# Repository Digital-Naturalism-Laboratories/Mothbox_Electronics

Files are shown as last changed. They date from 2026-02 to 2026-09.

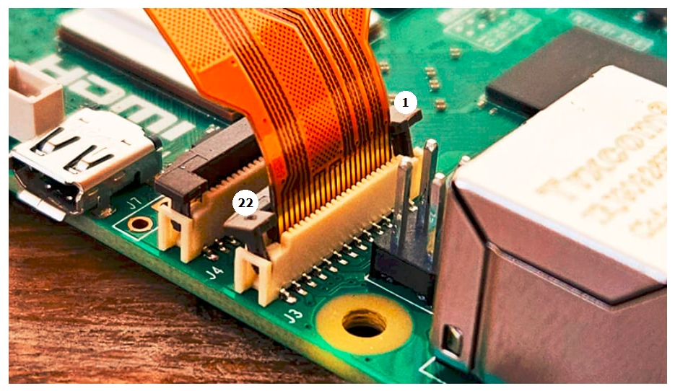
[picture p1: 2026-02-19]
Mothbox_PCBs/Mothbox_PCB_5.0.6/MothBox/Mothbox_5.0.4/RPi5-HATplus-master/img/CSI2_FFC_numbering.jpg

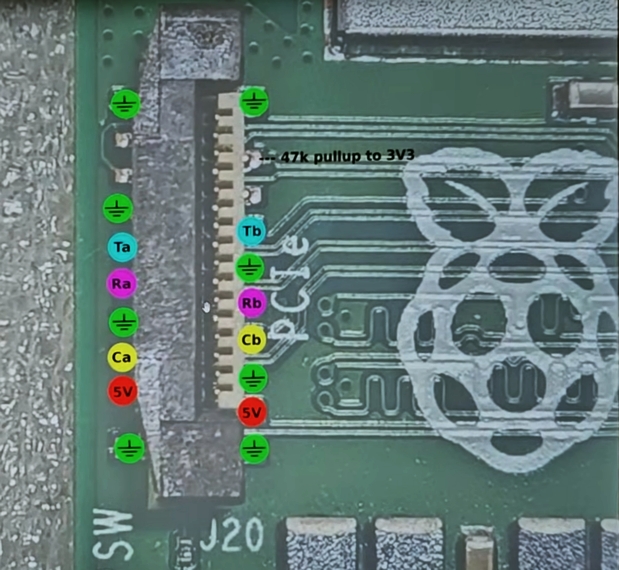
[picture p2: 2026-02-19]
Mothbox_PCBs/Mothbox_PCB_5.0.6/MothBox/RPi5-HATplus-master/img/George_Smart_PCIe_reversing.jpg

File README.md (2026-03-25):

# Mothbox_Electronics
This is where the electronics for the Mothbox are developed, such as the PCB! It's copied over from https://github.com/Digital-Naturalism-Laboratories/Mothbox/tree/main/Hardware/PCB so you can check that out if you want to see the full history!

Here's some current specs on the PCB 





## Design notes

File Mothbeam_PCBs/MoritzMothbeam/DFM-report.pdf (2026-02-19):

Single PCB View - Original

Top View | Bottom View

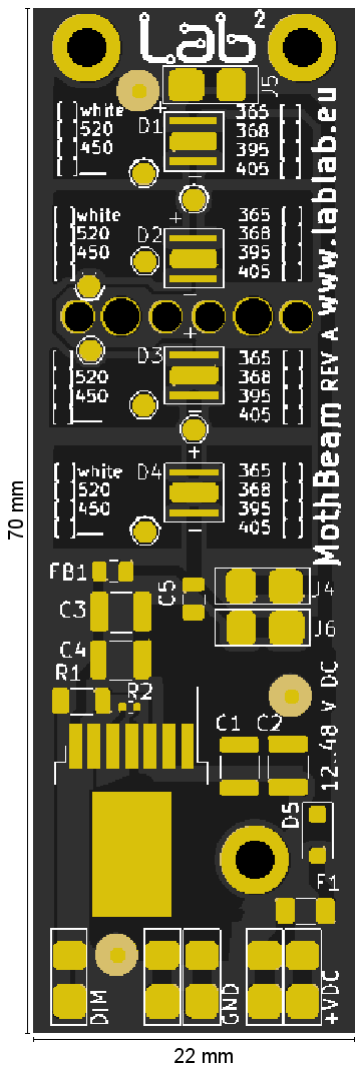
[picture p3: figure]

Summary - General - Original

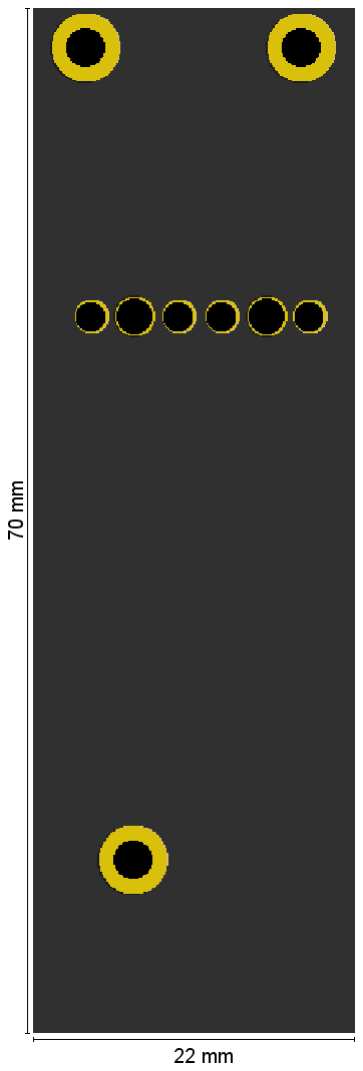
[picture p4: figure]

PCB Size | 22 mm x 70 mm | Customer Panel Size
PCB Thickness | 1.6 mm | Max. Aspect Ratio on PTH | 0.8
Copper Layers | 2 | Pressing Stages | 1
Surface Finish | unknown | Drill Hole Density | 58 Holes/dm²
Solder Mask | Both | Testable Points | 84
Solder Mask Color | Green | Min. SMD/BGA Size | 0.48 mm
Legend | Top Only | !HolesInPadPth! | No
Legend Color | White | !HolesInPadBlind! | No
Edge Connector Area | 0 dm² | Stacked Vias
Peeloff Mask | No | Castellated | No
Carbon Mask | No | Anomalies | No
1 | 2 | 3 | 4 | 5 | 6 | 7 | 8 | 9

Summary - Copper Layer Minima - Original

Type | Copper Width | Critical Copper Width

Trace Width Critical Trace

| | | | Width | Copper to Copper Clr. | Trace to Trace Clr. | Same Net Clr. | Ring | Copper to Outline Clr.
| mm | mm | mm | mm | mm | mm | mm | mm | mm
Outer | 0.250 | 0.250 | 0.250 | 0.250 | 0.235 | 0.341 | 0.380 | 0.150 | 0.314
Integr8tor v2023.12-240208 | Page1

The information on this document is not only based on files in a clearly defined format, but also on freely structured files and inference rules. CircuitHub strives to make it as accurate as possible, but it cannot guarantee the result in all situations. This information is used at the sole risk of its user.

Name | rev_57895.zip | Id. | 18720 - QED With Image Data
Report Generated on | Jul 8, 2024, 2:59:33 PM | Customer
Board Id | | Article Id

10 | 11 | 12

Summary - Copper Layer Minima - Original

Type | Copper to Plated Clr. | Copper to NPTH Clr.
!Min.Clr.Overal
l!

!Min.Clr.toPad! !Min.Clr.toTrac e!

!Min.Clr.toRegi
on!

!Min.Clr.Overal
l!

!Min.Clr.toPad! !Min.Clr.toTrac e!

!Min.Clr.toRegi
on!
mm | mm | mm | mm | mm | mm | mm | mm
Outer | 0.447 | 0.459 | 0.447 | >0.800
Inner

Summary - Sequences - Original

Type | Sequences | Tools | Min. End
| | | Dia. | Max. End Dia.
Holes | Routs | Ring on
| | | | | | | Outer

Ring on
Inner
| | | | | | | | Hole to Copper Clr.
mm | mm | mm | mm | mm
PTH | 1 | 3 | 2.000 | 2.700 | 9 | 0 | 0.150 | 0.447
Total | 1 | 3 | 2.000 | 2.700 | 9 | 0 | 0.150 | 0.447

Summary - Rout - Original

Type | Tools | Min. End Dia. | Max. End Dia. | Rout Length
| | | | | mm | | mm | mm
Plated
NPTH

Total

Board Id | Article Id

Stackup - Original

Pressing Stages | 1

Files - Original

Initial | Renamed | Function | Position | Color | Thickness
Base | Finished
| | | | | mm | mm
stencil-top.pho | paste-top | paste | top
silkscreen-top.pho | silk-top | silk | top | white | unknown | unknown
solder-mask-top.pho | mask-top | mask | top | black | unknown | unknown
copper-top.pho | top | outer | 1 | | | 0.035 | unknown
copper-bottom.pho | bot | outer | 2 | | | 0.035 | unknown
solder-mask-bottom.pho | mask-bot | mask | bottom | black | unknown | unknown
drill-npth.pho | pth_1 | plated | 1-2
drill.pho | pth | plated | 1-2
outline.pho | outline | cad_outline | none
silkscreen-bottom.pho | silkscreen-bottom_pho | empty | none
stencil-bottom.pho | stencil-bottom_pho | empty | none

PCB (Single) - Original

PCB Size | Outline Type | Outline Length | Outline Area | Copper Layers | PCB Thickness
mm x mm | | mm | dm² | | mm
22.000 x 70.000 | real | 184.000 | 0.1540 | 2 | 1.600

Customer Panel (Delivery Array, Assembly Panel) - Original

Original Image | Panel Size | Left | Right | Top | Bottom | X Spacing | Y Spacing | PCB's | Depanel Rout Length
| mm x mm | mm | mm | mm | mm | mm | mm | | mm

Thickness - Original

No license to generate this information.

Board Id | Article Id

Copper Layer Minima & Area - Original

File | Pos. Copper Width | Critical
Copper Width

Trace Width Critical Trace Width

Copper to
Copper Clr.

Same Net
Clr.

Copper Area

mm | mm | mm | mm | mm | mm | dm² | %
top | 1 | 0.250 | 0.250 | 0.250 | 0.250 | 0.235 | 0.380 | 0.0897 | 58
bot | 2 | >0.400 | >0.400 | >0.400 | >0.400 | 0.450 | >0.500 | 0.0081 | 5

Copper Layer Minima - Copper to Drill Minima - Original

File | Pos. | Ring | Copper to Drill Clr. | Copper to Outline Clr.
Overall | Via | Laser Via Comp. | Mech. | Plated | NPTH | Overall | to Pad | to Trace | to Region
mm | mm | mm | mm | mm | mm | mm | mm | mm | mm | mm
top | 1 | 0.150 | 0.150 | 0.447 | 0.314 | 0.314 | 1.243 | 1.054
bot | 2 | 0.150 | 0.150 | 0.600 | 0.314 | 0.314 | >1.600 | >1.600

Copper Layers - Copper to Copper Clearances - Original

File | Pos. | Copper to Copper Clr.
Overall | Pad to Pad | Pad to Track | Track to Track | Trace to Trace
mm | mm | mm | mm | mm
top | 1 | 0.235 | 0.309 | 0.235 | 0.341 | 0.341
bot | 2 | 0.450 | 0.450 | >0.500 | >0.500 | >0.500

Copper Areas - Original

Side | Total | Free of | Edge Connectors
Solder Mask
(as supplied)

Solder Mask
(open vias)
Gold Mask Silver Mask | Fingers | Finger Size | Total Area

dm²

dm²

dm²

dm²

dm² | mm x mm | dm²
Top (incl. 1/2 plated holes and routs) | 0.0911 | 0.0321 | 0.0321
Bottom (incl. 1/2 plated holes and routs) | 0.0094 | 0.0094 | 0.0094
Total (incl. plated holes and routs) | 0.1005 | 0.0415 | 0.0415 | 0
Plated holes and routs | 0.0106 | 0.0106 | 0.0106
Top (without plated holes and routs) | 0.0858 | 0.0268 | 0.0268
Bottom (without plated holes and routs) | 0.0041 | 0.0041 | 0.0041
Total (without plated holes and routs) | 0.0899 | 0.0309 | 0.0309

Drill Tools - Original

File | Tool
Nr.
Span | Type | Function Method Filled Via | Counter | Dia. | Tol. - | Tol. + Holes
in PCB

Routs
in PCB

Double
Hits

Predrill
Hits
mm | mm | mm
pth | 10 | 1-2 PTH | comp. | mech. | unknown unknown | 2.700 0.000 0.000 | 3 | 0 | 0 | 0
pth_1 | 10 | 1-2 PTH | comp. | mech. | unknown unknown | 2.000 0.000 0.000 | 4 | 0 | 0 | 0
pth_1 | 11 | 1-2 PTH | comp. | mech. | unknown unknown | 2.500 0.000 0.000 | 2 | 0 | 0 | 0
Board Id | Article Id

Drill Tools - Drill vs Copper - Original

File | Tool
Nr.
Span | Type | Function Method | Dia. Ring on
Outer

Ring on
Inner

Min.
Pad
Size

Via in
Pad

Plated to Copper Clr.
!Min.Clr
.Overall
!

!Min.Clr
.toPad!

!Min.Clr
.toTrac
e!

!Min.Clr
.toRegi
on!
mm | mm | mm | mm | mm | mm | mm | mm
pth | 10 | 1-2 PTH | comp. | mech. | 2.700 >0.800 | > 4.300 | >0.800 | >0.800 | >0.800 | >0.800

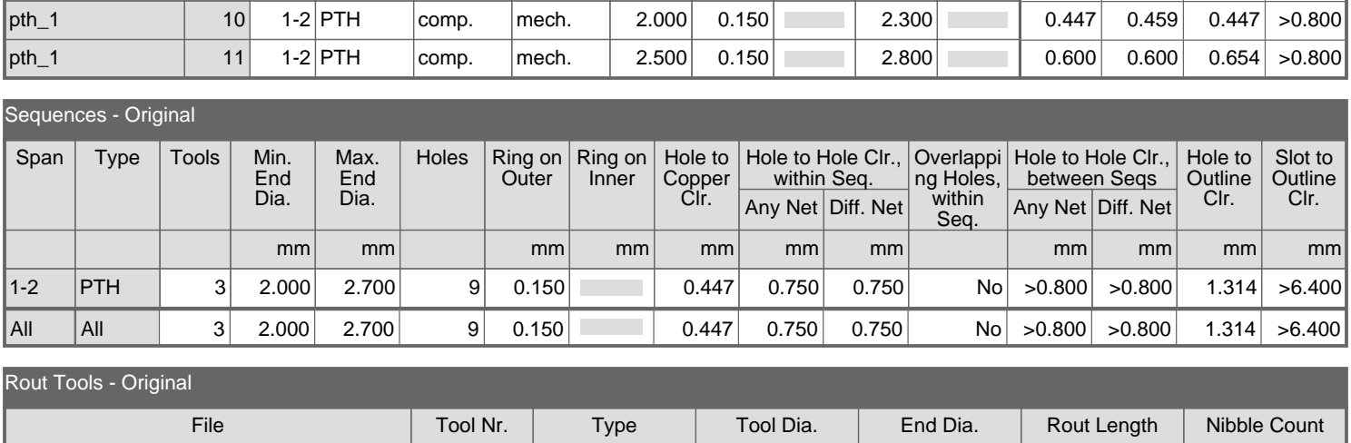
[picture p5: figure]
pth_1; 1-2 PTH; comp.; mech.; Sequences - Original; Span; Type; Tools; Min.; End Dia.; Max. End Dia.; Holes Ring on Outer; Ring on Inner; Hole to Copper Clr.; Hole to Hole Clr., within Seq.; Overlappi ng Holes, within Seq.; Hole to Hole Clr., between Seqs; Hole to Outline Clr.; Slot to Outline; Clr. Any Net Diff. Net; Any Net Diff. Net; PTH; All; Rout Tools - Original; File; Tool Nr.; Tool Dia.; Rout Length; Nibble Count

mm | mm | mm

Routed Holes - Original

File | Hole Nr. | Instances | X Size | Y Size | Rout Length | Nibble Count
mm | mm | mm

Sequences Analysis - Original

File | Pos. Stacked
Vias
| Overlap ped Vias | Via Plug Clr.
Top Tool | Bottom Tool
Top Drill File | Tool Nr. | Dia. | Bottom Drill File Tool Nr. | Dia.
| | mm | | mm | | mm

SMD (Incl. BGA) - Original

| SMD (Incl. BGA) | SMD (Excl. BGA) | | | BGA
Side | Pads | Min. Pad Pitch of Min.
| Pad | Solder Mask Defined Pads
Pads | Pads | Min. Pad | Min. Pitch | All Tracks
| | | | | Centered | Drilled Pads
mm | mm | mm | mm
Top | 66 | 0.480 | 2.770 | 0 | 66 | 0
Bottom | 0 | | | 0 | 0 | 0
Both | 66 | | | 0 | 66 | 0
Board Id | Article Id

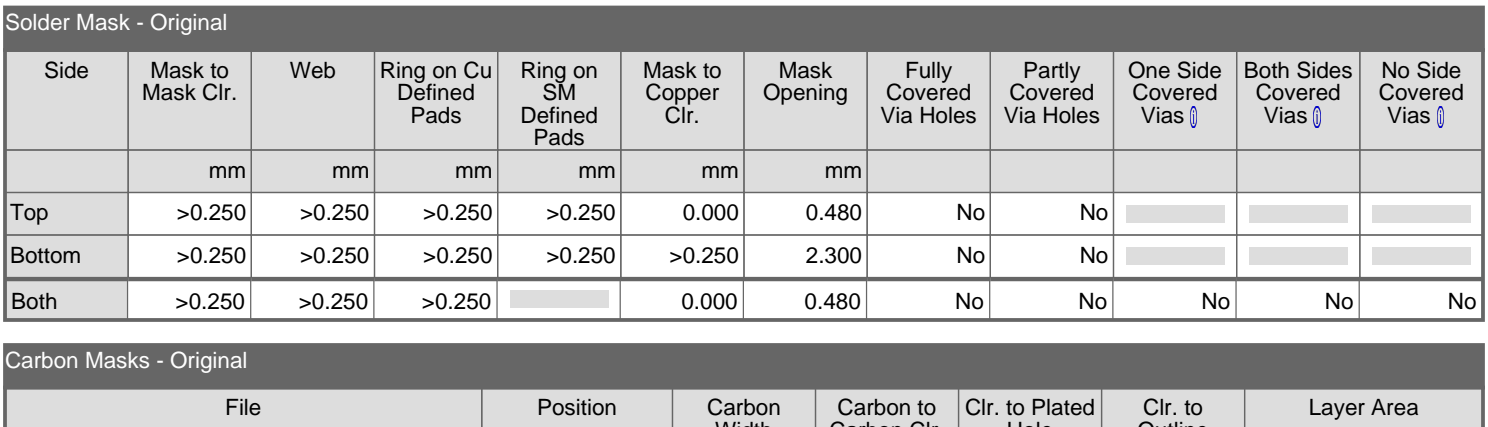
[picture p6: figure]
Solder Mask - Original; Side; Mask to; Mask Clr.; Web; Ring on Cu; Defined Pads; Ring on SM Defined Pads; Mask to Copper Clr.; Mask Opening; Fully Covered Via Holes; Partly Covered Via Holes; One Side Covered Vias; Both Sides Covered Vias; No Side Covered Vias; Top; Bottom; Both; Carbon Masks - Original; File; Position; Carbon; Carbon to; Clr. to Plated; Clr. to; Layer Area

Width

Carbon Clr.

Hole

Outline
mm | mm | mm | mm | dm² | %

Peeloff Masks - Original

File | Position | Min.
Peelable
Width

Peelable to
Peelable Clr.

Clr. to Plated
Hole

Clr. to
Outline

Layer Area

mm | mm | mm | mm | dm² | %

Legend Layers - Original

File | Position | Legend Width | Legend to
Legend Clr.

Legend to
(Comp/SMD/BGA)
Pad Clr.

Layer Area

mm | mm | mm | dm² | %
silk-top | top | 0.100 | 0.009 | 0.049 | 0.0126 | 8

Gold Layers - Original

File | Position | Gold to Gold Clr. | Clr. to Outline | Layer Area
mm | mm | dm² | %

Heatsink Layers - Original

File | Position | Heatsink to
Heatsink Clr.
Clr. to Outline | Layer Area
mm | mm | dm² | %

Scoring - Minimum Clearance - Original

No license to generate this information.

Bare Board Test - Original

Side | Testable Points
(TPs)
Max. TP Density | SMD Pads | Min. SMD Pad | Pitch of Min.
SMD Pad

Edge Connector
Fingers

Number of Nets

TP/dm² | mm | mm
Top | 75 | 809 | 66 | 0.480 | 2.770 | 0
Bottom | 9 | 154 | 0 | 0
Both | 84 | 809 | 66 | 0 | 28
Board Id | Article Id

DFM Classes - Original

| | | Standard | Advanced
1 | 2 | 3 | 4 | 5 | 6 | 7 | 8 | 9
Track & Gap | Min Clearance (Track-Track / Track-Pad / Pad-Pad) | 0.235 | 0.300 | 0.250 | 0.200 | 0.150 | 0.130 | 0.120 | 0.100 | 0.075 | 0.060
| Min Track Width / Thermal Gap | 0.250 | 0.300 | 0.250 | 0.200 | 0.150 | 0.130 | 0.120 | 0.100 | 0.075 | 0.060
Ring for IPC Class 2 | Outer Min Layer Annular Ring | 0.150 | 0.250 | 0.220 | 0.200 | 0.150 | 0.130 | 0.120 | 0.100 | 0.075 | 0.060
| Inner Min Layer Annular Ring | | 0.250 | 0.220 | 0.200 | 0.150 | 0.130 | 0.120 | 0.100 | 0.075 | 0.060
Aspect Ratio | Max Aspect Ratio for Plated Hole | 0.800 | 8.000 | 8.000 | 8.000 | 8.000 | 10.000 | 10.000 | 10.000 | 10.000 | 10.000
Drill - Cu | Distance PTH to PTH | 0.750 | 0.600 | 0.500 | 0.400 | 0.350 | 0.300 | 0.300 | 0.275 | 0.250 | 0.230
Cu Thickness | Max Cu Thickness that can be etched | | 0.175 | 0.140 | 0.105 | 0.070 | 0.070 | 0.035 | 0.035 | 0.035 | 0.017
Solder Mask | Solder Mask Annular Ring | 0.000 | 0.100 | 0.075 | 0.050 | 0.050 | 0.050 | 0.050 | 0.040 | 0.030 | 0.010
| Solder Mask SolderWeb | | 0.150 | 0.125 | 0.100 | 0.100 | 0.100 | 0.100 | 0.080 | 0.075 | 0.075

Input Remarks - Original

Gerber import: Invalid coincident draw, continuing without cleanup 'copper-top.pho'
Layer does not contain any image data (demoted to 'empty') 'silkscreen-bottom_pho'
Layer does not contain any image data (demoted to 'empty') 'stencil-bottom_pho'
Gerber Job File import: DISCREPANCY: Extra top layers mismatch between Gerber Job File and current job stackup.
Gerber Job File import: OMITTED: $.MaterialStackup[6] not added to layer attributes because corresponding layer could not be found.

Customer and Job Identification - Original

Customer
Customer | Contact Person
Email

Customer and Job Identification - Original

Job
Article Id | | Board Id
DPMX Output Path | CH

Comments - Original

Board Id | Article Id

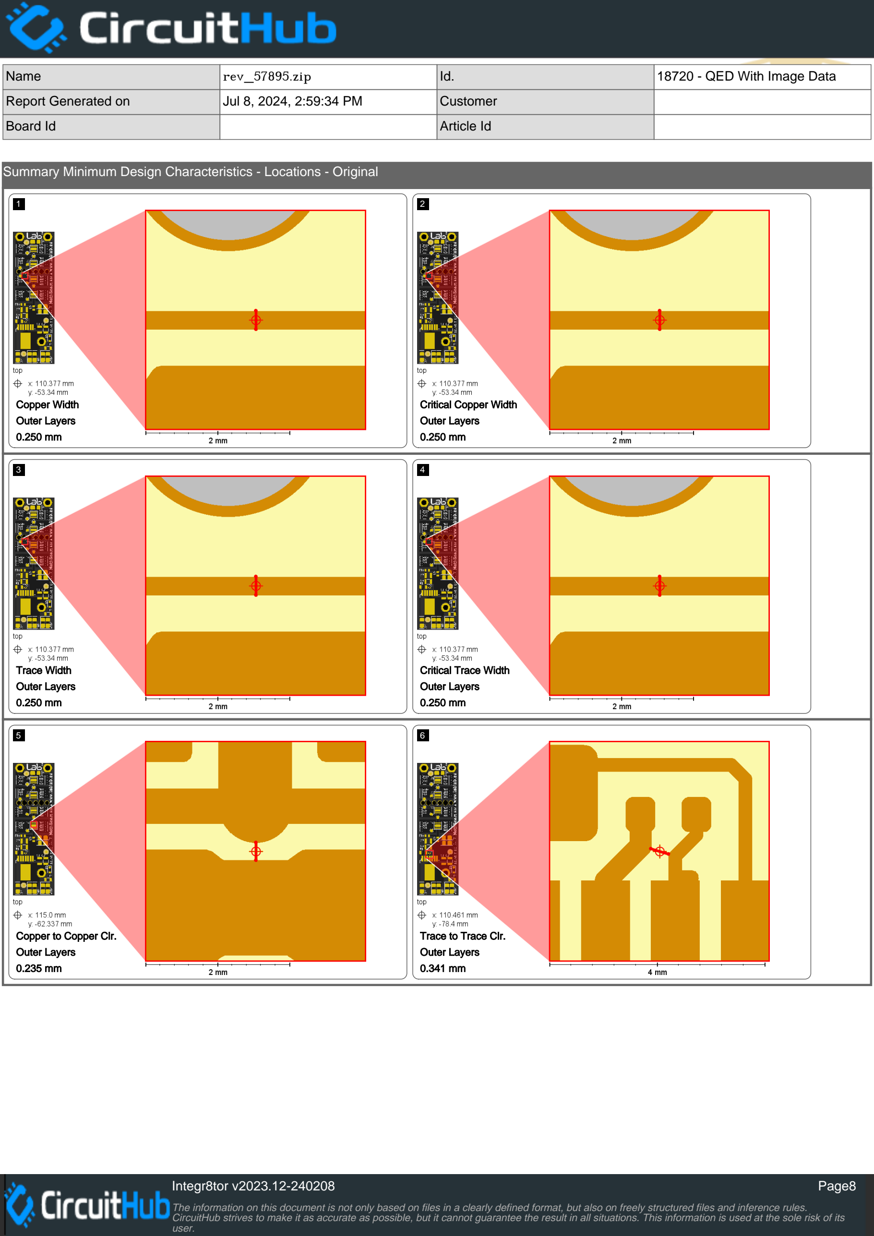
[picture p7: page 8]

1 | 2
3 | 4
5 | 6

Summary Minimum Design Characteristics - Locations - Original

Copper Width
Outer Layers
0.250 mm

Critical Copper Width
Outer Layers
0.250 mm

Trace Width
Outer Layers
0.250 mm

Critical Trace Width
Outer Layers
0.250 mm

Copper to Copper Clr.
Outer Layers
0.235 mm

Trace to Trace Clr.
Outer Layers
0.341 mm
Report Generated on | Jul 8, 2024, 2:59:34 PM | Customer
Board Id | | Article Id

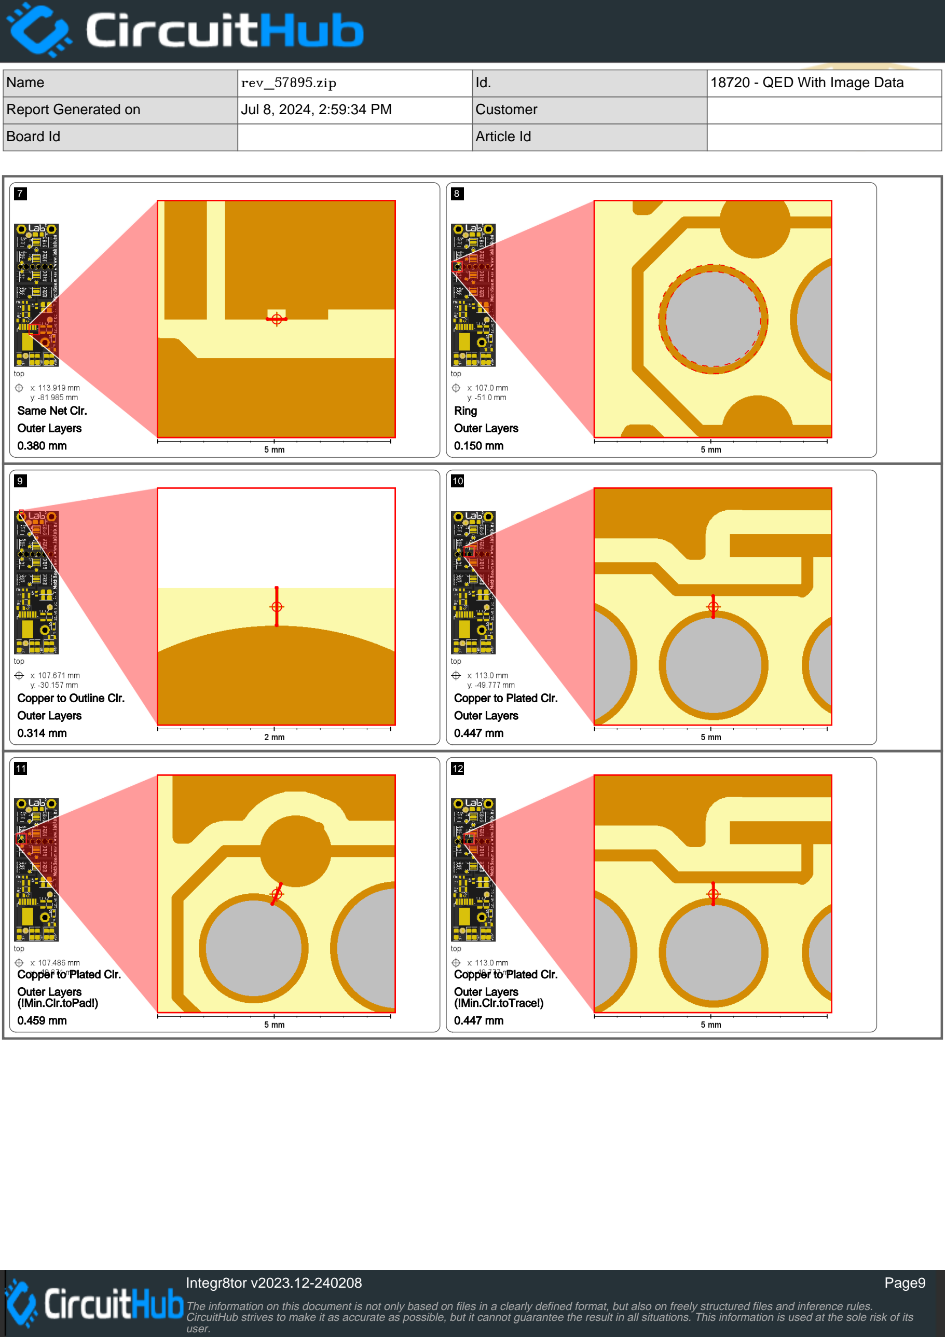
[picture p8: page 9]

7 | 8
9 | 10
11 | 12

Same Net Clr.
Outer Layers
0.380 mm

Ring
Outer Layers
0.150 mm

Copper to Outline Clr.
Outer Layers
0.314 mm

Copper to Plated Clr.
Outer Layers
0.447 mm

Copper to Plated Clr.
Outer Layers
(!Min.Clr.toPad!)
0.459 mm

Copper to Plated Clr.
Outer Layers
(!Min.Clr.toTrace!)
0.447 mm
Report Generated on | Jul 8, 2024, 2:59:34 PM | Customer
Board Id | | Article Id

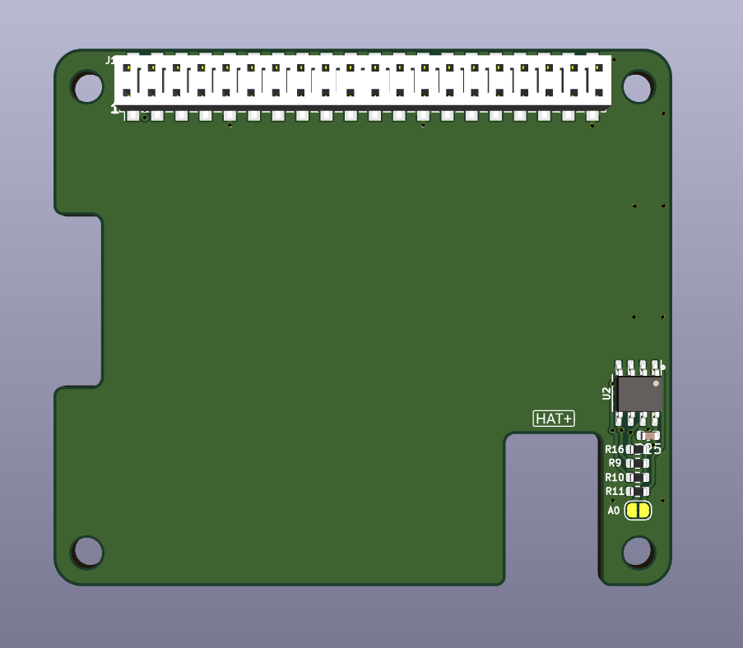
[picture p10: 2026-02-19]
Mothbox_PCBs/Mothbox_PCB_5.0.6/MothBox/Mothbox_5.0.4/MothBox_5.0.3/RPi5-HATplus-master/img/HATPlus_Template.png

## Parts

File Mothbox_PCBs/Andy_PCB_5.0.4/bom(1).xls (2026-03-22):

Comment | topDesignator | bottomDesignator | Footprint | JLCPCB Part #
5A47uH |  | L1 | L_Chilisin_BMRG00131360 | C497913
LTR-303ALS-01 | U18 |  | Lite-On_LTR-303ALS-01 | C364577
XL-5730UWC-05 | LED1,LED10,LED11,LED12,LED13,LED14,LED15,LED16,LED17,LED18,LED19,LED2,LED20,LED21,LED22,LED23,LED24,LED25,LED26,LED27,LED28,LED29,LED3,LED30,LED31,LED32,LED33,LED34,LED35,LED36,LED37,LED38,LED39,LED4,LED40,LED41,LED42,LED43,LED44,LED45,LED46,LED47,LED48,LED49,LED5,LED50,LED51,LED52,LED53,LED54,LED6,LED7,LED8,LED9 |  | LED-SMD_3P-L5.7-W3.0-RD | C2843887
AP30P30Q |  | Q1,Q10,Q13,Q8 | PDFN3333-8_L3.1-W3.2-P0.65-LS3.4-BL | C471913
10uF | C1,C19,C20,C21 | C10,C11,C17,C18,C8 | C_0603_1608Metric | C19702
100K |  | R38,R41,R42 | R_0603_1608Metric | C25803
3.0K |  | R3,R34 | R_0603_1608Metric | C4211
KH-6X6X5H-STM |  | SW2 | KEY-SMD_4P-L6.0-W6.0-P4.50-LS10.0-TL | C592734
GPs5pinPM2.54-1*5 |  | U8 | PinSocket_1x05_P2.54mm_Vertical | C5116488
10K | R11,R9 | R1,R19,R2,R21,R27,R31,R35,R36 | R_0603_1608Metric | C25804
Hours3 |  | U12,U10,U14,U13,U11 | SW-SMD_SMXS-08K-TP | C5439767
0.033R/1% |  | R4 | R_2512_6332Metric | C875726
YJQ10N2A | Q3,Q7 | Q4,Q5,Q6,Q9 | U-DFN2020-6_L2.0-W2.0-P0.65-BL | C919558
PCA9555PW |  | U15,U16,U9 | TSSOP-24_4.4x7.8mm_P0.65mm | C128392
Conn_1.25mm |  | J5 | CONN-SMD_3P-P1.25_DF13C-3P-1.25V | C88352
18R | R10,R12,R13,R14,R15,R16,R17,R18,R20,R22,R23,R24,R25,R26,R28,R37,R7,R8 |  | R_1210_3225Metric | C422378
RASPBERRY_PI_5 | U5 |  | EPAPER_PinHeader_2x20_P2.54mm_Vertical | C5224014
INA219BIDCNT |  | U3 | SOT-23-8 | C87469
DS18B20U |  | U17 | MSOP-8_L3.0-W3.0-P0.65-LS4.9-BL | C695836
SK54C |  | E1 | SMC_L6.9-W5.9-LS8.0-RD | C5449119
GPS4pin2.54-1*4P |  | H1 | PinSocket_1x04_P2.54mm_Vertical | C2718488
XL4015E1 |  | U2 | TO-263-5_TabPin3 | C51661
470uF50V |  | C14,C16 | CAP-SMD_BD12.5-L13.0-W13.0-RD | C90272
Green |  | D3 | LED_0603_1608Metric | C965804
DB141V-2.54-4P |  | J1,J2,J3,J4 | CONN-TH_4P-P2.54_DIBO_DB141V-2.54-4P | C2898746
AO3400A |  | Q2 | SOT-23 | C2938367
7Atrip |  | F2 | Fuse_2920_7451Metric | C22363536
4.7K |  | R29,R30,R33,R39,R5,R6 | R_0603_1608Metric | C23162
100R |  | R32 | R_0603_1608Metric | C21189
0.1uF | C13 | C2,C3,C5,C12,C15,C4,C6,C7,C9 | C_0603_1608Metric | C14663
18V |  | D1,D2,D4 | D_SOD-123 | C382948
FemaleInvSocketPi2.54-2*20 |  | U7 | HDR-TH_40P-P2.54-H-F-R2-C20-W8.5 | C2897440
PZ254R-12-8P | H10,H8,H9 |  | HDR-TH_8P-P2.54-H-M-R2-C4-S2.54 | C7501618

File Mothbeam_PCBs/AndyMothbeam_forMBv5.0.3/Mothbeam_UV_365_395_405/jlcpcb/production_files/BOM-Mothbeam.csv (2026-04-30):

Comment | Designator | Footprint | LCSC | Quantity
5.1 1/3 W | R1,R2,R3,R4,R5,R6,R9 | R_0603_1608Metric | C2907045 | 7
BCR421U | U1,U2,U3 | SOT-23-6_L2.9-W1.6-P0.95-LS2.8-BL | C194382 | 3
LED1 | D1 | LED-SMD_3P-L3.5-W3.5-R-RD-C | C2833504 | 1
LED2 | D2 | LED-SMD_3P-L3.5-W3.5-R-RD-C | C2833576 | 1
LED3 | D3 | LED-SMD_3P-L3.5-W3.5-R-RD-C | C2833578 | 1
SW_DIP_x04 | SW2 | SW-SMD_8P-L6.7-W5.4-P1.27-LS8.5 | C319050 | 1
X6511FRS-04-C85D30 | CN1 | HDR-SMD_4P-P2.54-H-F | C5142237 | 1

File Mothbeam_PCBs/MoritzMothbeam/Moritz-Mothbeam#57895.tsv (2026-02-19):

Description | ID | Manufacturer | Manufacturer Part Number | Supplier | Supplier Part Number | Reference Designators | Line Quantity | Order Quantity | Unit Price | Order Price | Legacy ID | Mounting Type
DNP | DNP |  |  |  |  | H4,H5,H6,H7,H8,H9,TP8,TP6,TP4,TP2,TP7,TP1,TP3,TP5,R2,H2,H3,FID1,FID2,FID3
Rectifier Diode Schottky 1A Automotive 2-Pin SOD-123F T/R / DIODE SCHOTTKY 60V 1A SOD123F | NEXPERIA/PMEG6010CEH,115 | Nexperia | PMEG6010CEH,115 | Newark | 75R0892 | D5 | 1 | 22 | 0.1050 | 2.3100 |  | Surface mount
Fuse Chip Fast Acting 1A 32V SMD Solder Pad 1206 Glass T/R VDE/cULus | SCHURTER/3413.0216.22 | Schurter | 3413.0216.22 | Digi-Key | 486-1144-6-ND | F1 | 1 | 9 | 0.9380 | 8.4420 |  | Surface mount
Ultraminiature Slim Contact; Poke-In Connector; SMT; Wire-to-Board; 20-24 AWG | TC/2834171-3 | TE Connectivity | 2834171-3 |  |  | J6,J4,J5,J2,J8,J3,J1,J7 | 8 | 50 | 0.0504 | 2.5200 |  | Surface mount
Uv Emitter, 365Nm, Uva, 1W, Top View Smd Rohs Compliant: Yes |Wurth Elektronik 15335337AA350 | W/15335337AA350 | Würth Elektronik | 15335337AA350 | Digi-Key | 732-15335337AA350DKR-ND | D1 | 1 | 5 | 21.3080 | 106.5400 |  | Surface mount
Single Color LED, Ultra Violet, Water Clear, 2.6mm | W/15335339AA350 | Würth Elektronik | 15335339AA350 |  |  | D3,D2 | 2 | 10 | 8.4700 | 84.7000 |  | Surface mount
Single Color LED, Ultra Violet, Water Clear, 2.6mm | W/15335340AA350 | Würth Elektronik | 15335340AA350 | Mouser | 710-15335340AA350 | D4 | 1 | 5 | 17.2200 | 86.1000 |  | Surface mount
WPME-LDHM LED Step Down High Current Module | W/172946001 | Würth Elektronik | 172946001 | Digi-Key | 732-6218-6-ND | U1 | 1 | 5 | 9.9680 | 49.8400 |  | Surface mount
WE-CBF Ferrite Bead 0805 1500Ohm 1000mA | Wurth Elektronik 742792097 | W/742792097 | Würth Elektronik | 742792097 | Digi-Key | 732-4649-1-ND | FB1 | 1 | 15 | 0.2940 | 4.4100 |  | Surface mount
0.1μF ±10% 100V Ceramic Capacitor X7R 0805 (2012 Metric) | W/885012207128 | Würth Elektronik | 885012207128 | Digi-Key | 732-12244-6-ND | C5 | 1 | 15 | 0.1232 | 1.8480 |  | Surface mount
4.7μF ±10% 50V Ceramic Capacitor X7R 1210 (3225 Metric) | W/885012209048 | Würth Elektronik | 885012209048 | Mouser | 710-885012209048 | C1,C2,C3,C4 | 4 | 24 | 1.8200 | 43.6800 |  | Surface mount
GENERAL PURPOSE CHIP RESISTOR Metal Glaze/thick Film, 0.25W, 0ohm, Surface Mount, 1206 | YAGEO/RC1206JR-070RL | Yageo | RC1206JR-070RL | Newark | 26M6809 | R1 | 1 | 100 | 0.0182 | 1.8200 |  | Surface mount

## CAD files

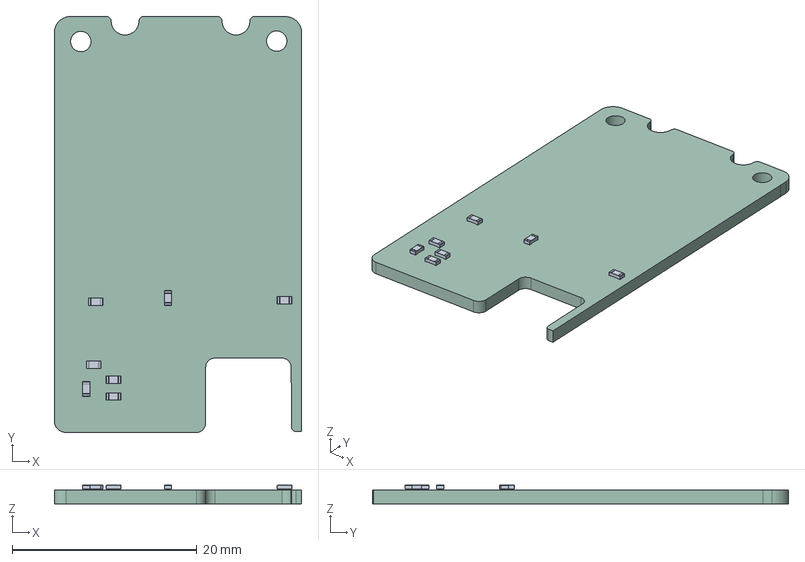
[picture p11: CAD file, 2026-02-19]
Mothbeam_PCBs/AndyMothbeam_forMBv5.0.1/Mothbeam_UV_365_395_405/Mothbeam-v5.0.1.step
26.8 x 45.0 x 2.04 mm
R_0603_1608Metric x 7
SOT-23-6_L2.9-W1.6-H1.5-LS2.8-P0.95 x 3
Mothbeam_PCB

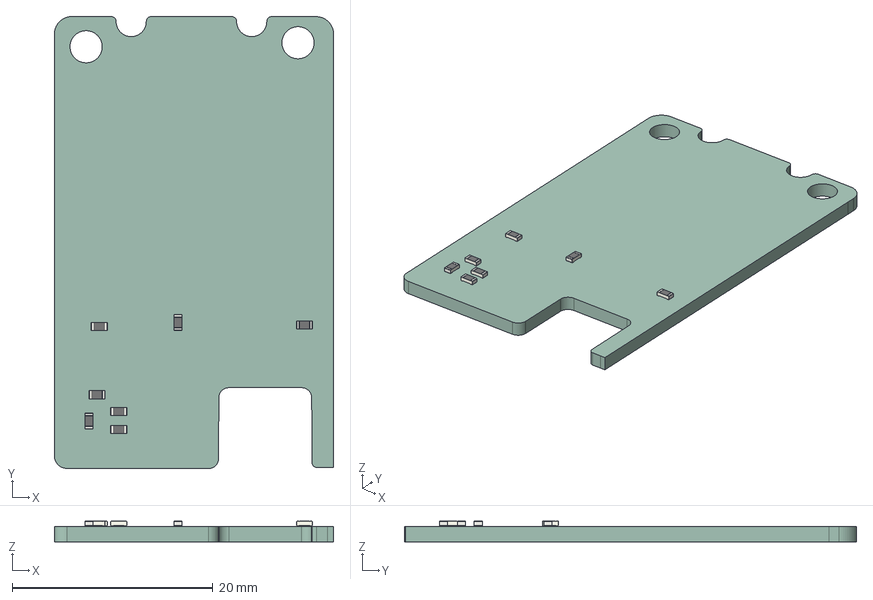
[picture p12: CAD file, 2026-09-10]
Mothbeam_PCBs/AndyMothbeam_forMBv5.0.3/Mothbeam_UV_365_395_405/Models_And_Designs/Mothbeam.step
27.8 x 45.0 x 2.04 mm
R_0603_1608Metric x 7
Mot78B0_PCB

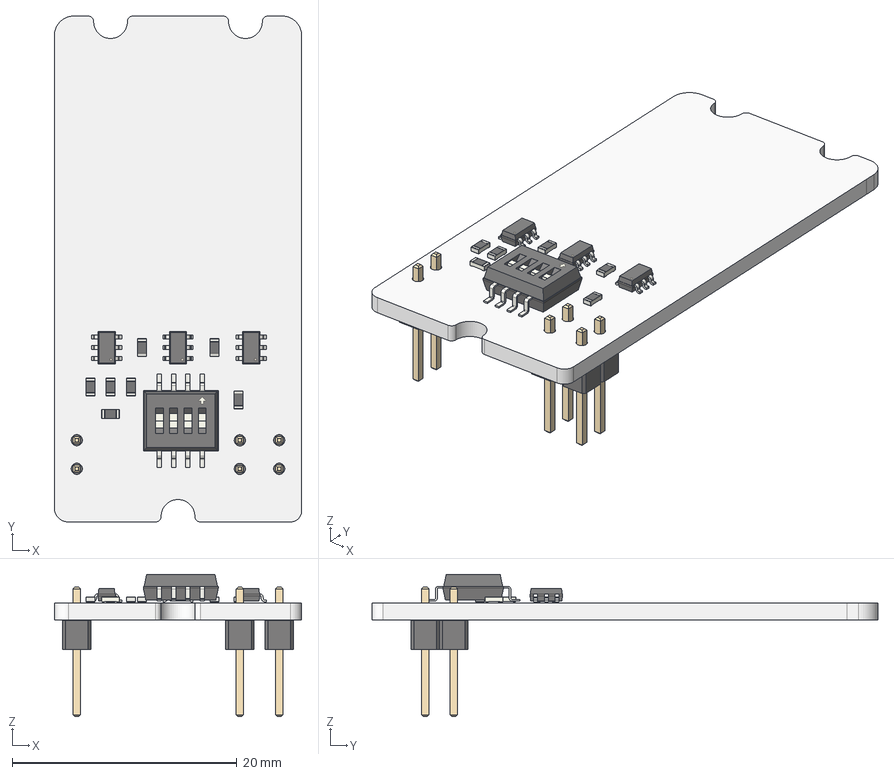
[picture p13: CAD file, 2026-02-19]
Mothbox_PCBs/Mothbox_PCB_5.0.6/MothbeamAttractor/MothbeamAttractor.step
22.0 x 45.0 x 12.7 mm
SW_DIP_SPSTx04_Slide_KingTek_DSHP04TS_W7.62mm_P1.27mm
R_0603_1608Metric x 7
SC-74-6_1.55x2.9mm_P0.95mm x 3
PinHeader_1x02_P2.54mm_Vertical x 3
MothbeamAttractor_PCB

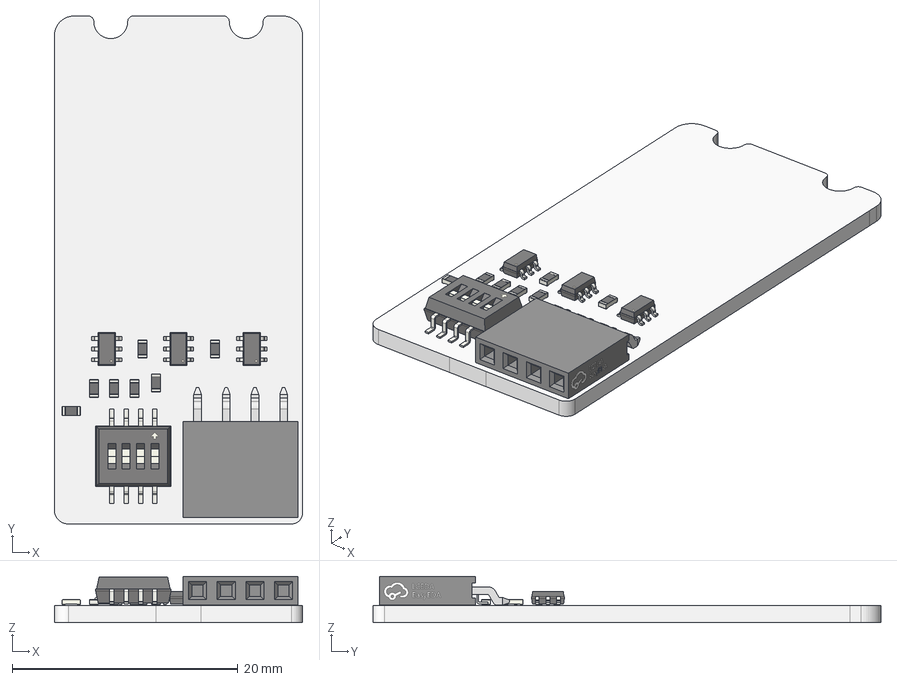
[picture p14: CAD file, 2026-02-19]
Mothbox_PCBs/Mothbox_PCB_5.0.6/MothbeamAttractor_FemaleHeader/MothbeamAttractorFemale.step
22.0 x 45.0 x 4.12 mm
SW_DIP_SPSTx04_Slide_KingTek_DSHP04TS_W7.62mm_P1.27mm
R_0603_1608Metric x 7
SC-74-6_1.55x2.9mm_P0.95mm x 3
HDR-SMD_4P-P2.54-H-F
MothbeamAttractor_PCB

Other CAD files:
Mothbox_PCBs/Mothbox_PCB_5.0.6/MothBox/Mothbox_5.0.4/CAD/MothBox_v5.0.1_FreeCad_Outline.FCStd
Mothbox_PCBs/Mothbox_PCB_5.0.6/MothBox/CAD/MothBox_v5.0.1_FreeCad_Outline.FCStd
Mothbox_PCBs/Mothbox_PCB_5.0.6/MothBox/Mothbox_5.0.4/MothBox_5.0.3/CAD/MothBox_v5.0.1_FreeCad_Outline.FCStd

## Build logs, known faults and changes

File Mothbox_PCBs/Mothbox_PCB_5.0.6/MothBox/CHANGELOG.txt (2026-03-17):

Project Name: MothBox Main PCB

PCB Versions:
-------------
Version 5.0.5:
Production:  PCBWAY, 2 Layers, 1.6mm, Green, 238mmx141mm 
Date: 2026-03  

Major Changes:
Done: Added second set of holes for mounting battery
Done: added highlights on battery mounting holes
Done: added PCBway logo for pcb sponsorship
Done: Changed labelling on switches to make them confuse JLC people less

Version 5.0.4:
Production:  JLCPCB, 2 Layers, 1.6mm, Green, 238mmx141mm 
Date: 2025-12-  

Major Changes:
Done: reverse Q8
Done: update zener diodes: D1+D2+D4 from 6.8V to 18V so they can cope better with 36V input voltages. Add a 100K ohm resistor to help with lower voltages
Done: Changed footprints of d1 d2 d4 to SOD 123 for bigger diode (AQ)
Done: swapped out C14+C16 for smaller 470uF 50V SMD Caps.  The 1000uF ones are too high and easily damaged
Done: swapped out R32 0R to 100R so that the RPi voltage is reduced from 5.40V to 5.25V

Minor changes:
Done: Change Attractor Mounting holes to m3 from m2.5 to make it easier to zip tie (AQ)
Done: Added 3D models for capacitors (AQ)
Done: Scootch SN QR code a bit so there's space for text code + QR code (AQ)
Done: rotate LED 49 to just give it a bit more breathting room away from attractor 2 (AQ)
Done: Moved Battery attaching zip tie holes around to avoid box conflict, and better battery holding (AQ)
Done: add some extra label to Documentation QR code
Done: add extra label to 12V testpoint to clarify that it's under software control
Done: minor Ground layer revamps
Done: added extra text to Power supply schematic to clarify 5V volt supply/resistor selection
Done: added a note about cutting JP1 if people want to measure the current

Version 5.0.3:
Production:  JLCPCB, 2 Layers, 1.6mm, Green, 238mmx141mm 
Date: 2025-11-20-ish  (uploaded by Andy to JLCPCB)

Major Changes:
Done: swap out the 12V vgs JMTV210P02A P-MOSFETs (Q1, Q8, Q10) for 20V Vgs based AP30P30Q - C471913
Done: change fuse from 1812 3A to 2920 7A?  Have to move IAN219 over a bit
Done: decrease IAN219 sense resistor from 0.1 ohm to 0.033 ohm
Done: Remove the D7, D6, D5, D2 ESD diodes.  Otherwise, increase from 12V, to 18V or 45V? 
Done: replace RPi 1000uF 5V cap with some 10uF caps. Could have used the original 470uF cap?
Done: rotate input power connector 90 deg.
Done: add a closed solder jumper across R4 so we can bypass the current measurements and save on the Voltage drop
Done: add zener to Q8 (12V isolater MOSFET).  Tt should have a 6.8V zener as well as it might have up to 36V across it?
Done: add reverse power protection to the 12V input after J1

Minor Changes:
Done: add double ++-- to the three side power green/orange connector labels and backside
Done: remove old MB: text label and box from backside
Done: fix R + L Flash LED labels to something like: L/R FLASH LED GND?
Done: add Talentcell Battery part numbers? (e.g. PB120B1) and larger font 
Done: whats happening to the two S/N boxes? (AQ - keep the square one, leave space below it (or move it to where it has space below)
Done: cleanup the EXT Temp Sensor label?
Done: move C5 and R33 label around the DS18B20 temp sensor box
Done: change 1.5V text to 1.5A on the external connector
Done: move the 'Active' label on the U11 switch to the RH side.
Done: add --++ label to front side of PCB on the input connector
Done: Add Aducam camera P/N text? Arducam 64MP OV64A40 OwlSight
Done: move and rotate 3V3 line MOSFET labels, + R36, C??
Done: rotate H1 + U8 GPS connector labels. PH: Note I ungrouped the 4 objects
No: make GPS box outline a bit smaller. PH: No, it's a footprint and outlines the size of the GPS board
Done: outline the Battery pack onto the silkscreen layer as a keep out zone
Done: decrease D1 zener from 10V to 6.8V. We need to be able to take 36V!!  Our zener can take up to 5mA.  We should pass 2.5mA max through 14.7K at 36V.
Done: bold up ambient light sensor text 
Done: rotate U18 ref label
Done: re-arrange front/back side graphics and text
Done: moved some of the traces a bit away from under the sides of the L1 inductor

Version 5.0.2:
Production:  JLCPCB, 2 Layers, 1.6mm, Green, 238mmx141mm 
Date: 2025-09-TBD  (uploaded by Andy)

Done: AQ- swapped green indicator LED (C72043) which LCSC says is discontinued  for  C2289 which is dirt cheap and plentiful
Done: AQ - change the user switch to use the ALWAYS on 3v3 power so that a user could always be able to push it, and then it could trigger a script to enable the other 3.3v
Done: AQ - scoot items out of where batteries might be
Done: Silkscreen - we should put the test point labels on both sides of the board
Done: add a user switch
Done: add a user LED
Done: MOSFET switch the entire 3V3 line out of the RPi connector to minimise 3.3V quiescent current usage. 
Done: add a SMD DS18B20 PCB temperature sensor
Done: add provision for an external DS18B20 temperature sensor. Need a 4.7K ohm resistor and a 1.25mm 3-pin connector
Done: remove 3V3 input leading to the ePaper hat connector as it has it's own built in 5V to 3V3 regulator
Done: Swap out the PCA9535 MUX to the PCA9555PW(UMW) as this has pullup resistors: C42420607
Done: fix the two Attractor 3 labels.  One should be #1
Done: can move attractor labels out from under the foot print?
Done: Move resistor R22 out from underneath Attractor 3 footprint
Done: 5v test point is awkwardly under an LED on one side
Done: Silkscreen of regulated 12v is reversed! (Double check other silkscreen labels)
Done: change R3 to a lower value (3K Ohm) so as to raise the voltage to 5.2V for the RPi
Done: add an extra resistor close to R3 (Vf power), so feedback voltage can be easier to fine tune
Done: swap out the BH1750FVI-TR LCSC: C78960 to the cheaper LTR-303ALS-01 ambient light sensor: C364577, US$0.38/ea, DFN-6(2x2)
Done: remove: GPIO4/pin8 from RPi-ePaper.  Reroute to DS18B20
Done: construct a stronger ground plain
Done: Add an extra 6 (2 x 3) Photo LEDs to PCB
Done: added Power input/Output direction arrows for each connector
Done: modified Serial Number Box shape - Andy added another switched it back because JLCPCB needs certain dimensions to automatically put the serial and QR code on

Version 5.0.1: 
Production:  JLCPCB, 2 Layers, 1.6mm, Green, 238mmx141mm 
Date: 2025-05-18 

Done: design and laid out by building on the 5.0.0 design and user feedback
Done: upgraded white LEDs to be twice as bright (500mW)
Done: replaced switch multiplexer IC's with i2C based IC's
Done: added an extra switch bank for another 8 hours of config options
Done: reversed ePaper screen so it's on the other side of PCB
Done: swapped out the MOSFETs for different and cheaper versions
Done: added a reverse polarity protection MOSFET to power input
Done: swapped out the green input connectors from a horizontal to vertical connectors
Done: swapped out the 0805 fuse to a larger 1812 6A fuse
Done: as there are now more i2C IC's on the bus, the i2C pullup resistor values where dropped to 4.7K ohm
Done: added a project URL QR code to the PCB
Done: general clean up of the schematic
Done: add a BH1750FVI-TR light sensor (second v5.0.1 version)

Version 5.0.0: 
Production:  JLCPCB, 2 Layers, 1.6mm, Green, 238mmx141mm 
Date: 2025-05-??

* designed and laid out by AndyQ

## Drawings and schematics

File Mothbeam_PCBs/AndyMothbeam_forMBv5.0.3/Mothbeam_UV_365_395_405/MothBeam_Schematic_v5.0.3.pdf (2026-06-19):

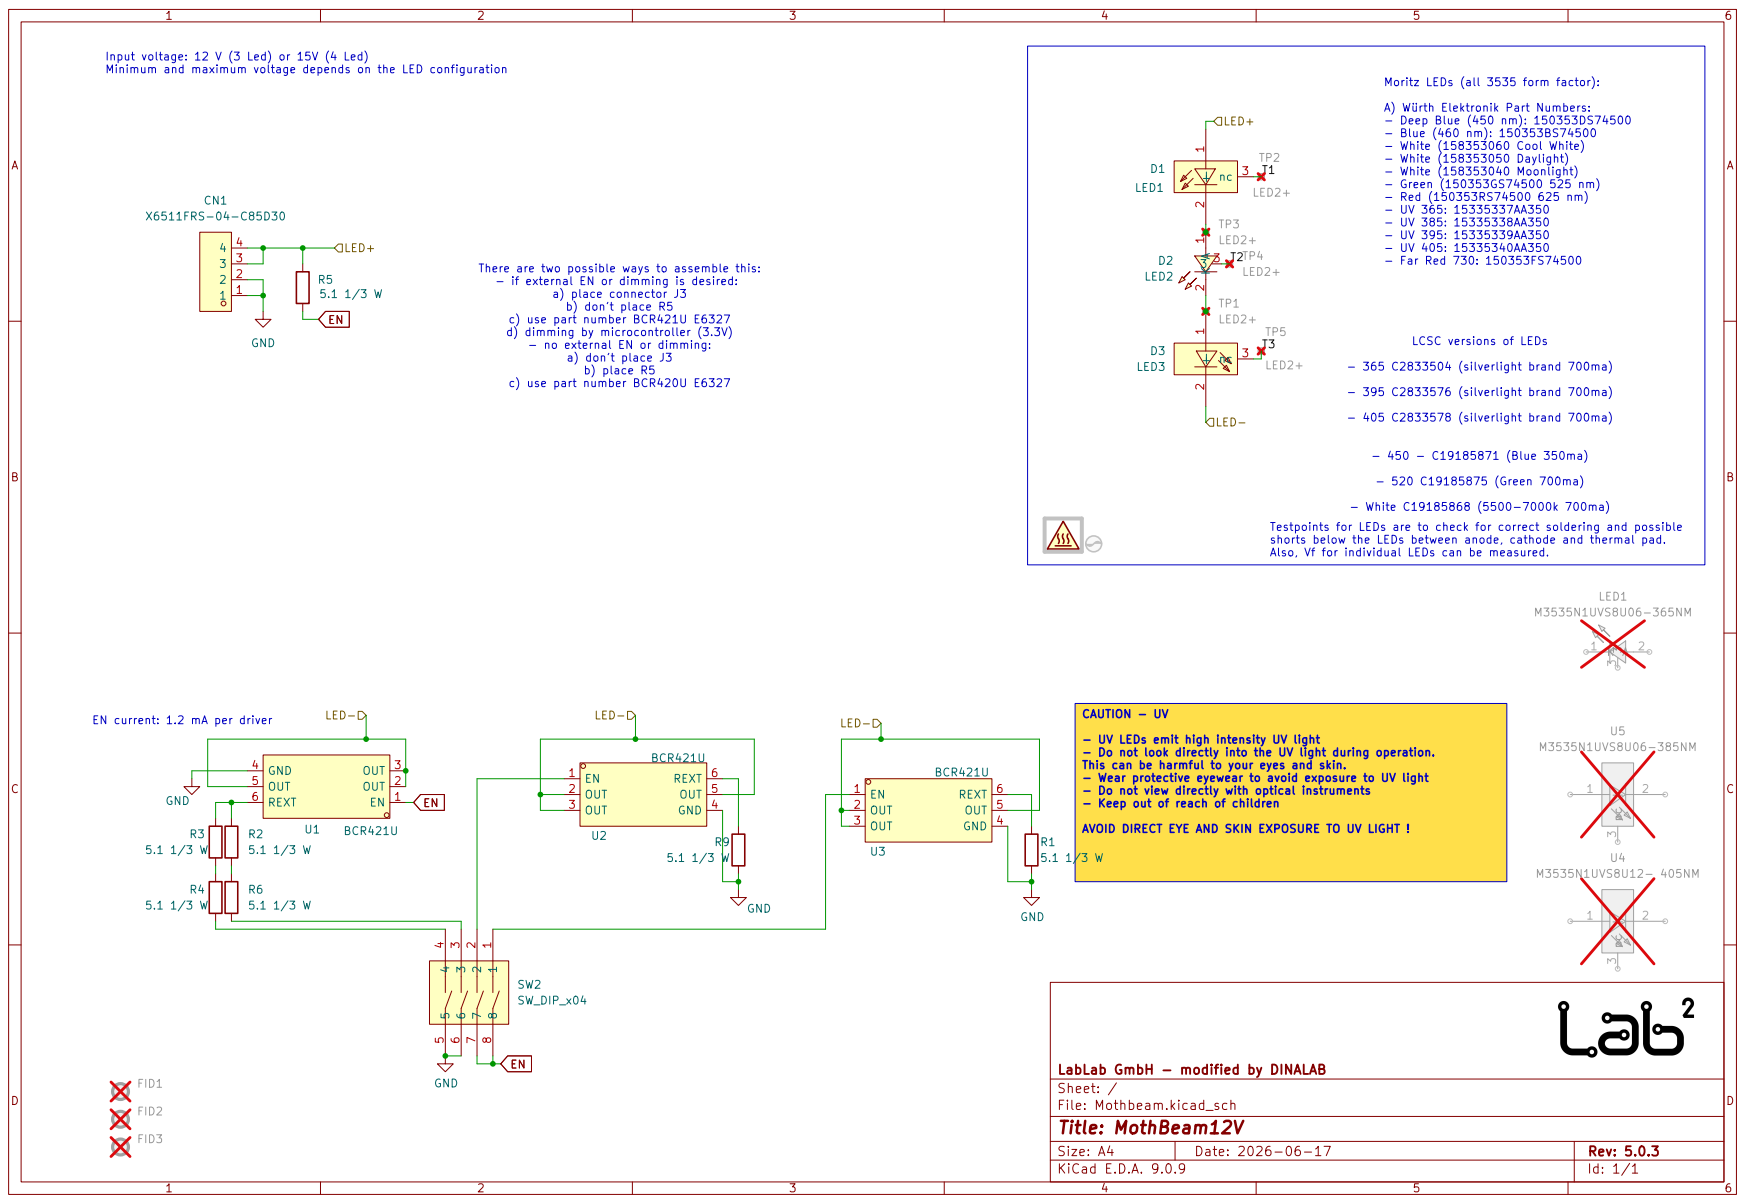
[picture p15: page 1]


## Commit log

2026-02-19 Moved from original mothbox repo
    [57895-CH0015da8d-TH-TOP.tsv, 57895-CH0015da8d.tsv, Adafruit INA219 STEMMA QT.brd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]
2026-03-17 initial new PCBway version of board
    [Adafruit INA219 STEMMA QT.brd, Adafruit INA219 STEMMA QT.sch, Adafruit_INA219_CurPowerMonitor.brd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]
2026-03-17 made PCBway pcb v5.0.5
    Major Changes:
    Done: Added second set of holes for mounting battery
    Done: added highlights on battery mounting holes
    Done: added PCBway logo for pcb sponsorship
    Done: Changed labelling on switches to make them confuse JLC people less
    [Adafruit INA219 STEMMA QT.brd, Adafruit INA219 STEMMA QT.sch, Adafruit_INA219_CurPowerMonitor.brd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]
2026-03-17 added "On" signifiers for switches
    [Mothbox_5.0.4.kicad_pcb]
2026-03-17 tweaks to PCBway 5.0.5
2026-03-18 new IC for 219 with smaller pads , ignoring zip files
    [Mothbox_5.0.4.kicad_pcb]
2026-03-19 tweaked incorrect descriptions for some parts
    [Mothbox_5.0.4.kicad_pcb, Power.kicad_sch]
2026-03-22 Fixed rotations and parts for JLC
    [BOM-Mothbox_5.0.4.csv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]
2026-03-25 Update README with PCB specs and images
    Added current specs and images for the PCB.
2026-03-31 fixed up gitignore
    [BOM-Mothbox_5.0.4.csv, BOM-Mothbox_5.0.5_noLogo.csv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]
2026-03-31 got rid of 5.0.3
    [Adafruit INA219 STEMMA QT.brd, Adafruit INA219 STEMMA QT.sch, Adafruit_INA219_CurPowerMonitor.brd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]
2026-03-31 production files going on
    [BOM-Mothbox_5.0.4.csv, BOM-Mothbox_5.0.5_noLogo.csv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]
2026-03-31 production files are there!
    [BOM-Mothbox_5.0.4.csv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]
2026-04-30 Update .gitignore to remove BOM file exclusions
    Removed exported BOM file patterns from .gitignore.
2026-04-30 Update .gitignore to remove BOM file exclusions
    Removed exported BOM file types from .gitignore.
2026-04-30 stop ignoring stuff
    [BOM-Mothbeam(1).csv, BOM-Mothbeam.csv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]
2026-04-30 got original files to show up for mothbeam
    [BOM-Mothbeam(1).csv, BOM-Mothbeam.csv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]
2026-06-17 added v5.0.3 of mothbeam
    [BOM-Mothbeam(1).csv, BOM-Mothbeam.csv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]
2026-06-17 add jlc gerbers for UV design
    [BOM-Mothbeam.csv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]
2026-06-17 remove old production files
    [BOM-Mothbeam(1).csv, BOM-Mothbeam.csv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]
2026-08-12 added new 5.0.6 placeholder
    [Adafruit INA219 STEMMA QT.brd, Adafruit INA219 STEMMA QT.sch, Adafruit_INA219_CurPowerMonitor.brd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]
2026-08-13 Added Holes for Attractor, Added Holes for corners instead of screws, widened pi hole
    [Mothbox_5.0.6.kicad_pcb]
2026-08-13 Passes Stricter DRC. Shifted Temp sensor. Rotated switches correctly
    [GPS.kicad_sch, Mothbox_5.0.6.kicad_pcb, Mothbox_5.0.6.kicad_sch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]
2026-08-15 Updated the Light sensor to a more abundant (and low light sensitive) part
    [BOM-Mothbox_5.0.6.csv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]
2026-08-17 Made a built in switch flipper
    [BOM-Mothbox_5.0.4.csv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]
2026-08-17 imported new spring terminal, but not used
    [Mothbox_5.0.6.kicad_pcb]
2026-08-17 Placed the august order for 30-40
    [Mothbeam-CuBottom.gbr, Mothbeam-CuTop.gbr, Mothbeam-EdgeCuts.gbr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]
2026-09-05 Starting to add holes back to mothbeams!
    [Mothbeam.kicad_pcb]
2026-09-05 added missing c14 c16 capacitors in
    [BOM-Mothbox_5.0.6.csv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]
2026-09-10 models for mothbeams
    [Mothbeam-v5.0.1.step, Mothbeam.kicad_pcb, Mothbeam.step]
2026-09-11 scooted hole a tiny bit
    [Mothbeam.kicad_pcb]
